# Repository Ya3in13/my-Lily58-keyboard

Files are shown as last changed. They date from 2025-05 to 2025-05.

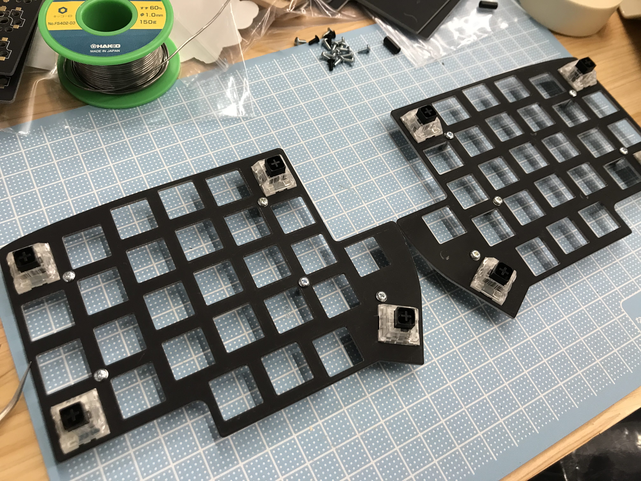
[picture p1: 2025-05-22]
Hardware/lily58/gerber-case/51967380-87a49680-24b2-11e9-80b9-a45564afc8cf.jpg

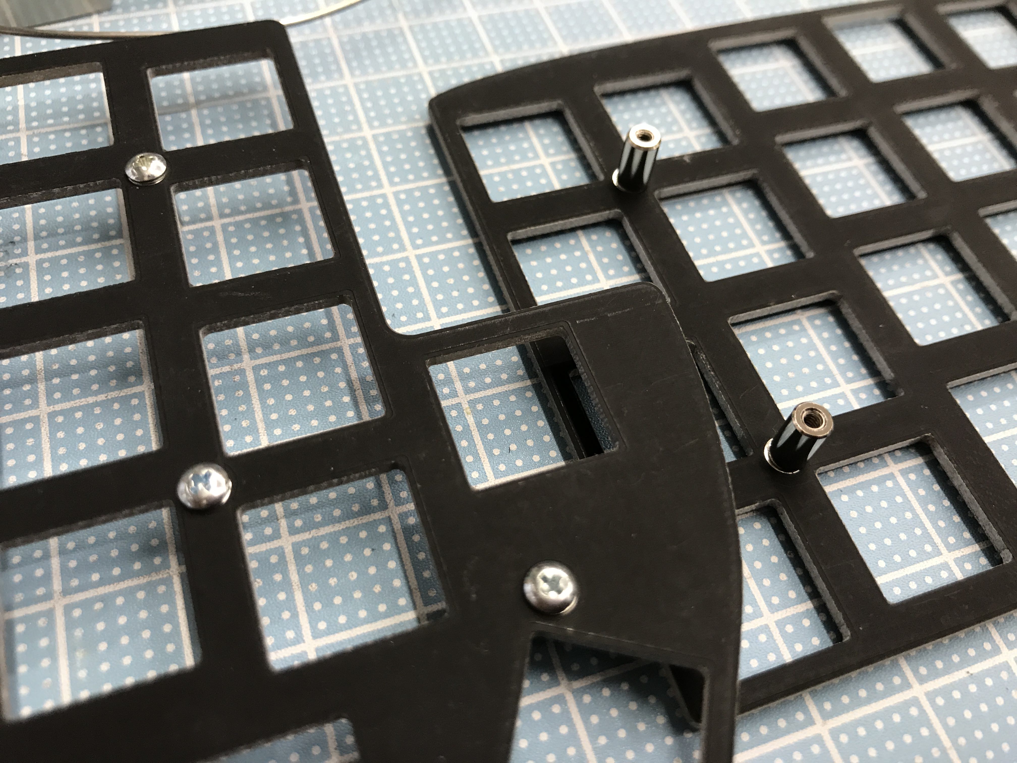
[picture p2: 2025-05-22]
Hardware/lily58/gerber-case/51967376-83787900-24b2-11e9-82a0-850556daccfc.jpg

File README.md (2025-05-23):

# my-Lily58-keyboard

## قطعات مورد نیاز

#  (راهنمای ساخت کیبورد لیلی۵۸)

این راهنما مراحل کامل مونتاژ و برنامه‌ریزی کیبورد **Lily58** را به زبان فارسی توضیح می‌دهد. لطفاً با دقت و طبق مراحل زیر پیش بروید تا از عملکرد صحیح کیبورد خود لذت ببرید.

---

## 📦 لیست قطعات

| نام قطعه | تعداد | توضیحات |
|---|---|---|
| PCB | 2 عدد | مدار چاپی اصلی |
| کیس | 1 ست (۴ عدد) | دو عدد با سوراخ برای سوئیچ‌ها، دو عدد ساده |
| ProMicro | 2 عدد | ترجیحاً همراه با |
| سوئیچ (MX / Choc) | 58 عدد | بسته به انتخاب نوع سوکت |
| سوکت سوئیچ | 58 عدد | برای نصب آسان سوئیچ‌ها |
| دیود 1N4148W | 58 عدد | نصب با جهت صحیح(به نوع smd با پارتنامبر T4) |
| کپ کیبورد | 58 عدد | ۱U |
| ماژول OLED | 2 عدد | برای نمایش اطلاعات لایه و وضعیت |
| سوییچ ریست | 2 عدد | Tact Switch کوچک |
| جک TRRS | 2 عدد | اتصال بین دو نیمه |
| فاصله‌دهنده M2 | 14 عدد | Choc: 4mm، MX: 7mm |
| پیچ M2 | 28 عدد | برای اتصال کیس و فاصله‌دهنده |
| کابل TRRS | 1 عدد | کابل AUX چهارپین |
| کابل Micro USB | 1 عدد | پیشنهاد می‌شود از نوع مگنتی باشد |

---

## 🛠️ مراحل مونتاژ

### 1. آماده‌سازی
- بردها **دوطرفه** هستند.
- با چسب کاغذی پشت و جلوی هر برد را مشخص کنید.

### 2. نصب دیودها
- نصب روی پشت برد.
- جهت دیود مطابق فلش PCB باشد.
- ابتدا یک پایه را لحیم کرده، سپس دیود را تنظیم و کامل لحیم کنید.

### 3. نصب سوکت سوئیچ‌ها
- نصب در پشت برد مانند دیودها.
- نوع سوکت (MX یا Choc) را با جایگاه مربوطه منطبق کنید.

### 4. نصب جک TRRS و دکمه ریست
- در جلوی برد نصب می‌شوند.
- با نوار چسب فیکس کرده و از پشت لحیم کنید.

### 5. نصب نمایشگر OLED
- ابتدا جامپرهای پشت ProMicro را برای OLED آماده کنید.
- سوکت OLED را روی برد نصب و لحیم کنید.
- ماژول OLED را وارد سوکت نمایید.

### 6. نصب ProMicro
- محل نصب متفاوت برای نیمه چپ و راست.
- اگر spring pin header موجود است، از آن استفاده کنید.(داخل ایران به پین هدر نظامی معروف هستند)
- منبع راهنما: [Helix ProMicro Guide](https://github.com/MakotoKurauchi/helix/blob/master/Doc/buildguide_en.md#pro-micro)

### 7. نصب فاصله‌دهنده‌ها
- ۴ عدد فاصله‌دهنده ۱۰mm کنار ProMicro قرار دهید.
- سایر فاصله‌دهنده‌ها را نیز با پیچ نصب کنید.

### 8. نصب سوئیچ‌ها و کیس
- کیس بالایی را روی برد قرار دهید.
- ابتدا چند سوئیچ مرکزی را برای تراز کردن قرار داده و لحیم کنید.
- سپس تمام سوئیچ‌ها را نصب کنید.

### 9. محافظ ProMicro
- محافظ آکریلیک را روی ProMicro قرار دهید.
- پلاستیک روی محافظ را جدا کرده و نصب کنید.

---

## 💻 برنامه‌ریزی و فلش
وارد [سایت ](https://config.qmk.fm/#/lily58/rev1/LAYOUT) زیر بشید و مدل مد نظر تون رو بسازید و یا من فایل دیفالت رو براتون توی ادرس زیر گذاستم.

my-Lily58-keyboard\Firmware\Firmware.hax

فایل نرم افزار برای اپلود فابل رو هم براتون توی ادرس زیر گذاشتم.

my-Lily58-keyboard\Firmware\qmk_firmware-lily58-rev1-lii.zip

🧪 تست عملکرد
اتصال دو نیمه با کابل TRRS.

اتصال کابل USB به نیمه چپ.

تست کلیدها.

چسباندن پدهای ضدلغزش به زیر بردها.

⚠️ مشکلات رایج
مشکل	راه‌حل
یک ردیف یا ستون کار نمی‌کند	لحیم‌کاری ناقص در ProMicro یا دیودها
یک کلید خاص عمل نمی‌کند	چک کردن سوکت، سوئیچ، یا دیود آن
حروف اشتباه وارد می‌شوند	زبان کیبورد در سیستم را به US تغییر دهید

مستندات کامل: QMK Documentation

🧷 منابع
Lily58 Official Repo

QMK Firmware

Build Guide (EN)

نویسنده: یاسین

تاریخ: اردیبهشت ۱۴۰۴

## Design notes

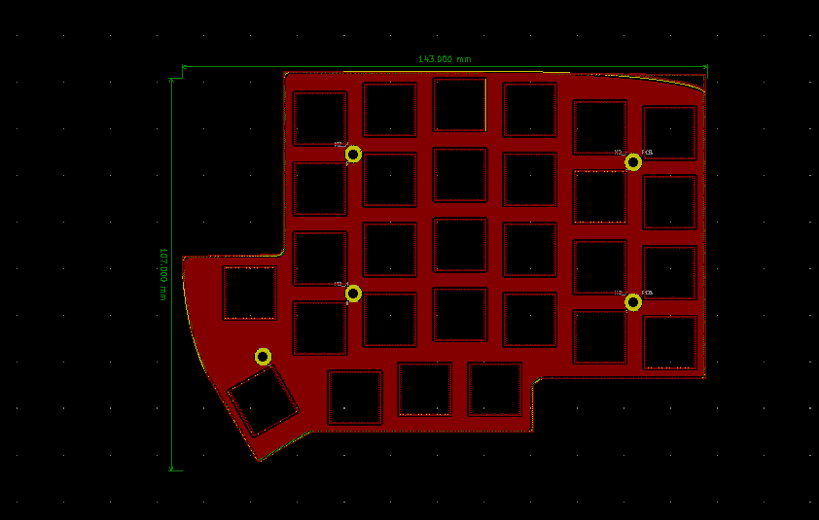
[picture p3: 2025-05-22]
Hardware/lily58/case/Screenshot 2025-02-01 000244.png

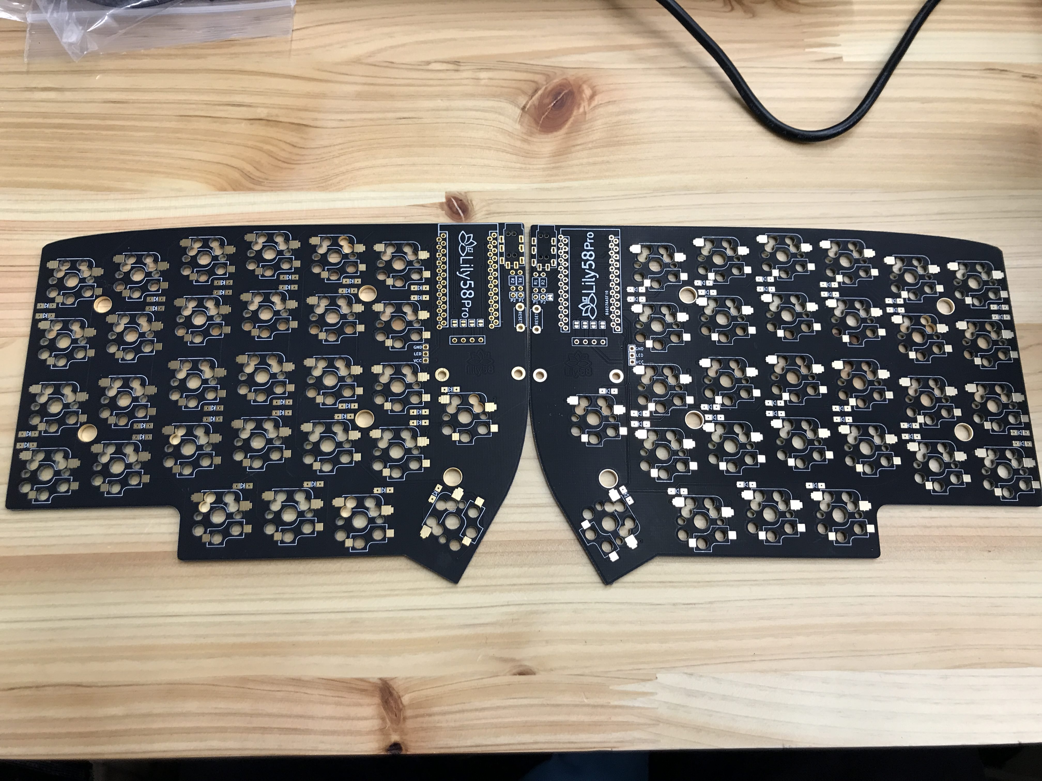
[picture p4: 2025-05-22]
Hardware/lily58/gerber-pcb/51967194-0947f480-24b2-11e9-860f-e45197cf0983.jpg

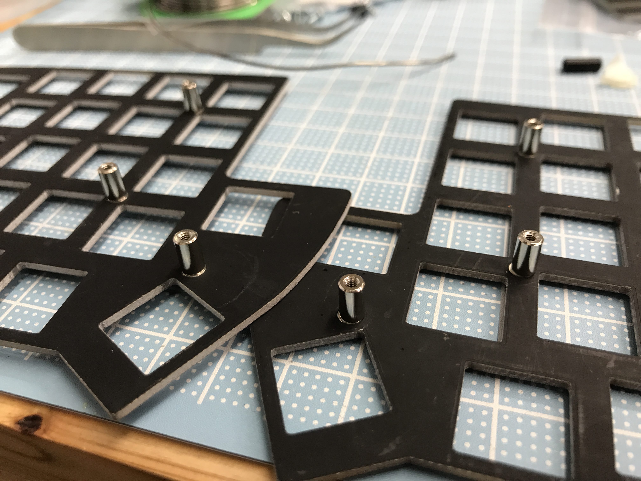
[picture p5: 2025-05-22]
Hardware/lily58/gerber-case/51967395-912dfe80-24b2-11e9-9cc7-b4520063f36c.jpg

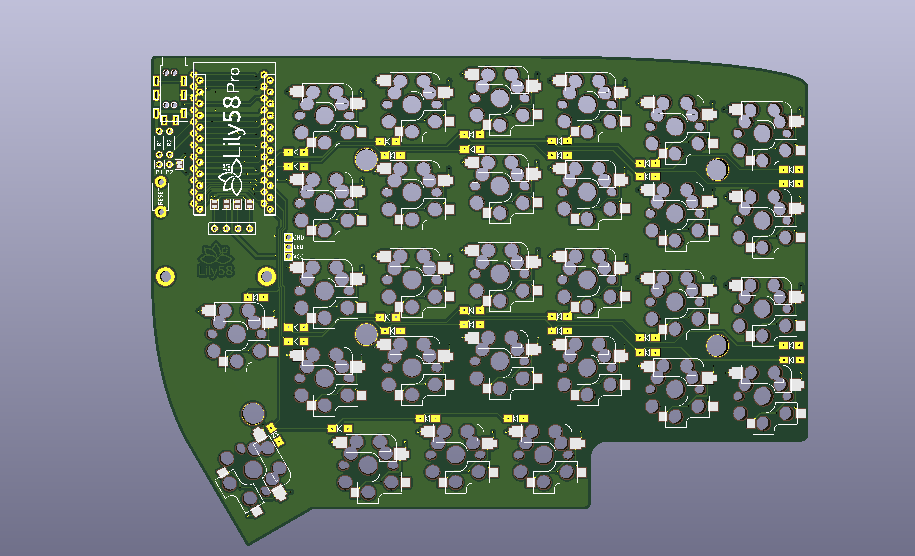
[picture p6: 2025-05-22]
Hardware/lily58/pcb/Screenshot 2025-02-01 000106.png

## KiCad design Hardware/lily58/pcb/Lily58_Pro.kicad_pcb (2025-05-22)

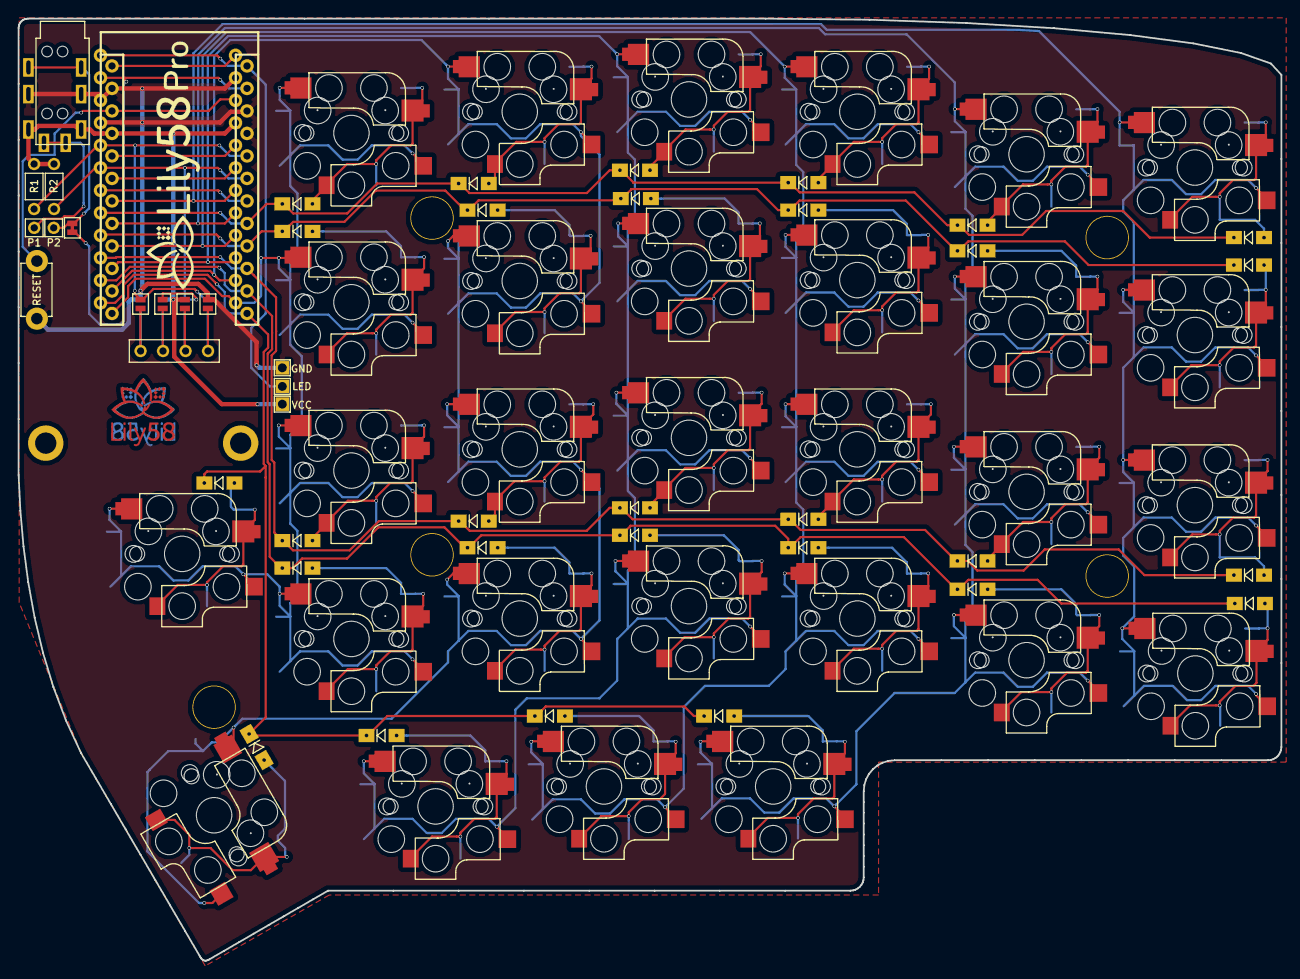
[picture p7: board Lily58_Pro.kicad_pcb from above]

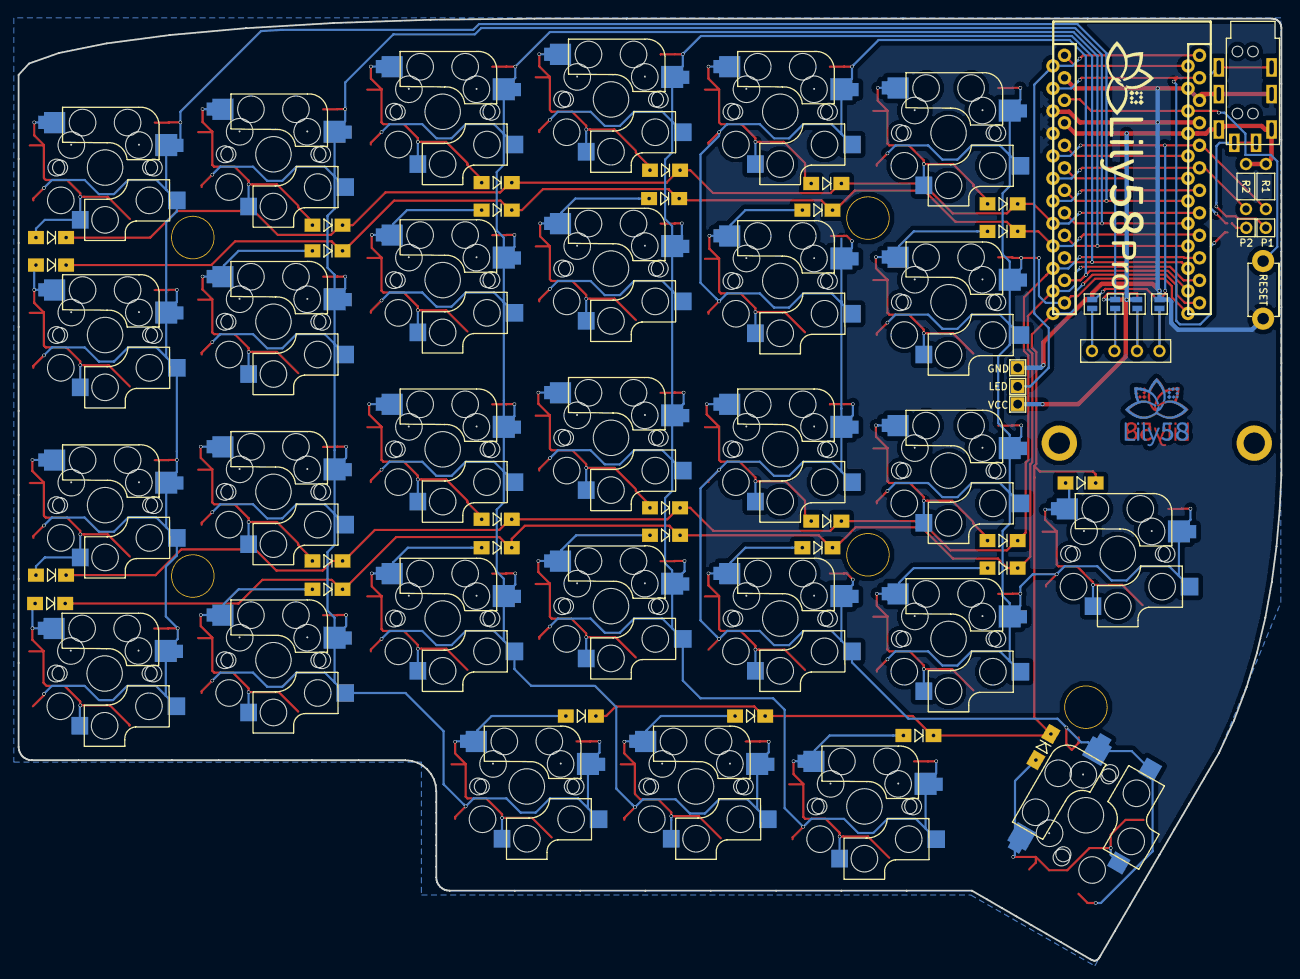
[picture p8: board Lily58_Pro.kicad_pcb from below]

Board: 2 copper layers, 142.5 x 106.3 mm, 83 parts (4 on the bottom side), 53 nets.

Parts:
D1, D2, D3, D4, D5, D6, D7, D8, D9, D10, D11, D12, D13, D14, D15, D16, D17, D18, D19, D20, D21, D22, D23, D24, D25, D26, D27, D28, D29: D; Diode_SOD123
J1: LED
J2: 4PIN; MJ-4PP-9
J3: OLED; OLED_4Pin
JP1, JP2, JP3, JP4, JP5, JP6, JP7, JP8: Jumper
P1, P2: i2c_pin; 1pin_conn
R1, R2: R; RESISTOR_mini
RSW1: SW_RST; TACT_SWITCH_TVBP06
SW1, SW2, SW3, SW4, SW5, SW6, SW7, SW8, SW9, SW10, SW11, SW12, SW13, SW14, SW15, SW16, SW17, SW18, SW19, SW20, SW21, SW22, SW23, SW24, SW25, SW26, SW27, SW28, SW29: SW_PUSH; CherryMX_KailhLowProfile_Hotswap_edge
TH1, TH2: HOLE; M2_HOLE_PCB
TH3, TH4, TH5, TH6, TH7: HOLE; HOLE_M2_TH
U1: ProMicro; ProMicro_rev2
W1: jumper; jumper_data

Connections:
DATA: U1.2, W1.1
GND: J1.3, J2.2, JP1.2, JP8.2, RSW1.1, U1.3, U1.4, U1.23
LED: J1.2, U1.1
unnamed: D1.2, SW1.2
unnamed: D2.2, SW2.2
unnamed: D3.2, SW3.2
unnamed: D4.2, SW4.2
unnamed: D5.2, SW5.2
unnamed: D6.2, SW6.2
unnamed: D7.2, SW7.2
unnamed: D8.2, SW8.2
unnamed: D9.2, SW9.2
unnamed: D10.2, SW10.2
unnamed: D11.2, SW11.2
unnamed: D12.2, SW12.2
unnamed: D13.2, SW13.2
unnamed: D14.2, SW14.2
unnamed: D15.2, SW15.2
unnamed: D16.2, SW16.2
unnamed: D17.2, SW17.2
unnamed: D18.2, SW18.2
unnamed: D19.2, SW19.2
unnamed: D20.2, SW20.2
unnamed: D21.2, SW21.2
unnamed: D22.2, SW22.2
unnamed: D23.2, SW23.2
unnamed: D24.2, SW24.2
unnamed: D25.2, SW25.2
unnamed: D26.2, SW26.2
unnamed: D27.2, SW27.2
unnamed: D28.2, SW28.2
unnamed: D29.2, SW29.2
unnamed: J2.3, P2.1, W1.2
unnamed: J2.4, P1.1
unnamed: J3.1, JP4.1, JP8.1
unnamed: J3.2, JP3.1, JP7.1
unnamed: J3.3, JP2.1, JP6.1
unnamed: J3.4, JP1.1, JP5.1
RESET: RSW1.2, U1.22
SCL: JP3.2, JP6.2, R2.2, U1.6
SDA: JP4.2, JP5.2, R1.2, U1.5
VCC: J1.1, J2.1, JP2.2, JP7.2, R1.1, R2.1, U1.21
col0: SW6.1, SW12.1, SW18.1, SW24.1, U1.18
col1: SW5.1, SW11.1, SW17.1, SW23.1, SW29.1, U1.17
col2: SW4.1, SW10.1, SW16.1, SW22.1, SW28.1, U1.16
col3: SW3.1, SW9.1, SW15.1, SW21.1, SW27.1, U1.15
col4: SW2.1, SW8.1, SW14.1, SW20.1, SW26.1, U1.14
col5: SW1.1, SW7.1, SW13.1, SW19.1, SW25.1, U1.13
row0: D1.1, D2.1, D3.1, D4.1, D5.1, D6.1, U1.8
row1: D7.1, D8.1, D9.1, D10.1, D11.1, D12.1, U1.9
row2: D13.1, D14.1, D15.1, D16.1, D17.1, D18.1, U1.10
row3: D19.1, D20.1, D21.1, D22.1, D23.1, D24.1, U1.11
row4: D25.1, D26.1, D27.1, D28.1, D29.1, U1.12

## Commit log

2025-05-22 fol fix
    [Lily58_Pro-B_Cu.gbl, Lily58_Pro-B_Mask.gbs, Lily58_Pro-B_SilkS.gbo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]
2025-05-22 Create hex-QMK Configurator.txt
    [hex-QMK Configurator.txt]
